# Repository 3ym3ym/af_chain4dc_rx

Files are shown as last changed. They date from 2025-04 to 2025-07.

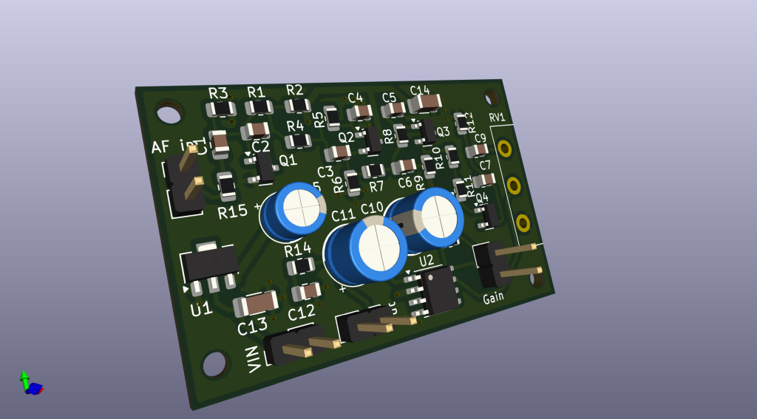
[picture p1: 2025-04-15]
aud_chain2_3d.png

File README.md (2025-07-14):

# af_chain4dc_rx
AF chain for DC receiver
aud_chain2

This little project was created to complete the standalone direct conversion (DC) receiver. Other parts of the receiver are:
 - Main board (input filter, quadrature mixer, AF preamps, phasing SSB demodulator). Si5351A board from Adafruit (or Aliexpress clone) is attached to it.
 - Control board. Can be any microcontroller running the qudrature VFO code. I am currently using RP2040 SuperMini, 0.96" SSD1306 OLED display and 360PPI optical encoder.

The idea behind the whole project is to build a high performance SSB/CW receiver using only cheap parts readily available from Aliexpress or other similar sources.

Included files are the KiCAD 9.0 project (schematic and PCB) which uses SMD footprints. It can be modified to use through hole footprints. All parts are available in TH variants.

The first stage is a simple CE amplifier, also used to set the bias point to the following filter stages. The gain (and the input impedance) is set by R15.

I picked the idea of the low-pass audio filter from Asshar Farhan, VU2ESE. The actual filter design was done using the online Filter Wizard tool from Analog Devices, then tweaked while simulating in LTSpice. The values listed in the schematic result in -3dB point about 2.0kHz. At 5kHz the attenuation is -50dB. I used 5% resistors and 10% capacitors. The frequency response is not as sharp as the simulated with the ideal values, but is good enough and I like the sound of SSB coming through the filter. I am not a CW guy, modifying the filter for CW is left as an exercise for the reader.

The final amplifier is a standard TDA2822 circuit, with a jumper to change the gain. It has significantly lower hiss than LM386 and the Chinese fakes seem to work well.

The circuit works down to 3V. I am using a cheap ME6209 3.3V LDO, which requires a good output bypass capacitor, otherwise there is a bit of ringing at the maximum volume (because of the feedback from the PA back to the input stage through the power rail). 100uF aluminum plus 10uF ceramic capacitors is not an overkill.

ME6209 claims to tolerate up to 18V input, which I haven't tested. The dropout is small enough to use a single LiIon cell as the input power source, or 12V if that is what you have in the receiver.

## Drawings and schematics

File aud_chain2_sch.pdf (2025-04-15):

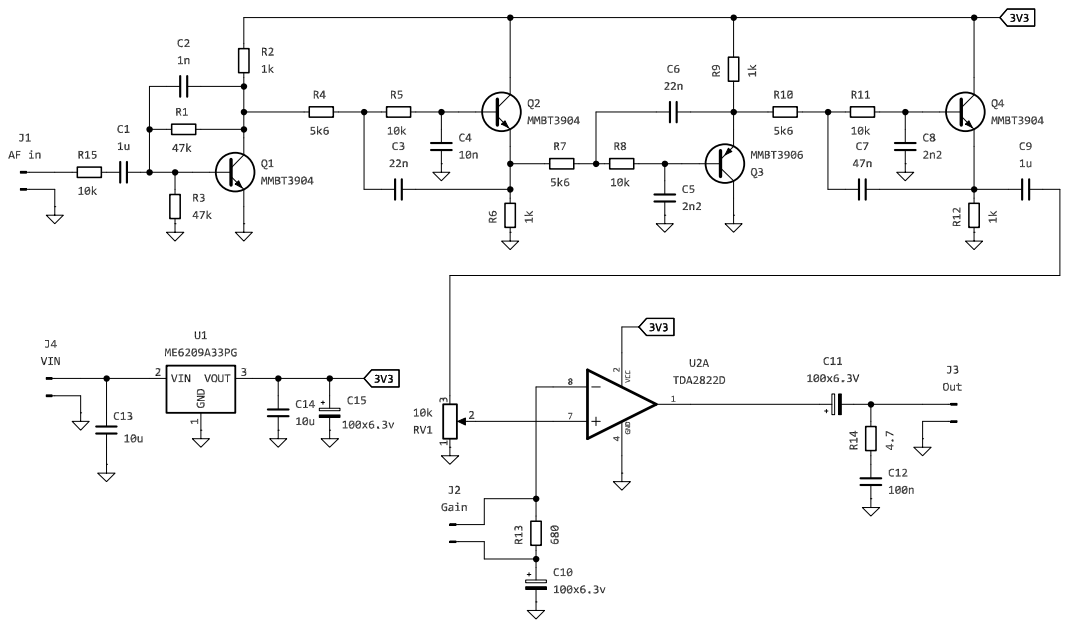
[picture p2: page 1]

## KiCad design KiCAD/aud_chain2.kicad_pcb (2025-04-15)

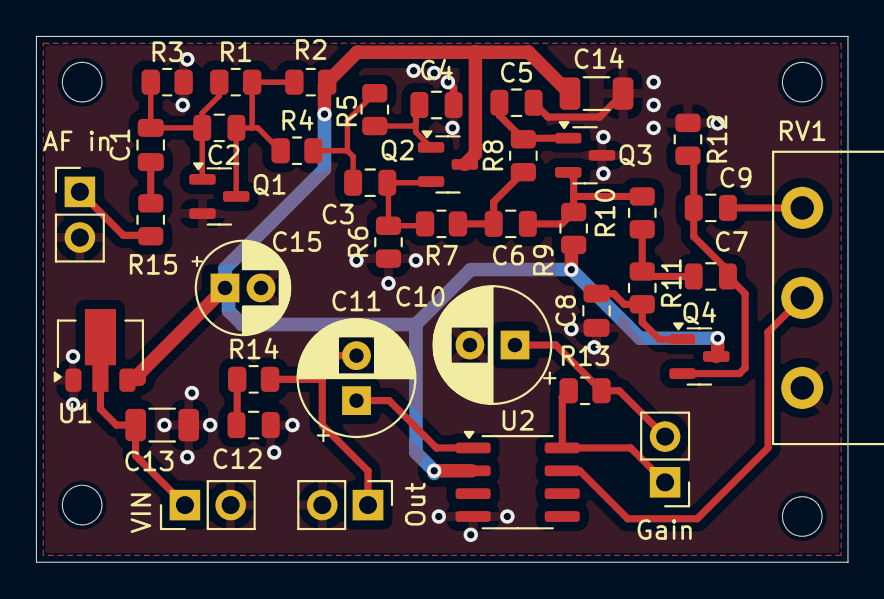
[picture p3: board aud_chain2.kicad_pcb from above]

Board: 2 copper layers, 45.1 x 29.2 mm, 41 parts (0 on the bottom side), 23 nets.

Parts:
C1, C9: 1u; C_0805_2012Metric
C2, C4: 1n; C_0805_2012Metric
C3, C6, C7: 22n; C_0805_2012Metric
C5: 10n; C_0805_2012Metric
C8: 15n; C_0805_2012Metric
C10: 100x6.3v; CP_Radial_D6.3mm_P2.50mm
C11: 100x6.3V; CP_Radial_D6.3mm_P2.50mm
C12: 100n; C_0805_2012Metric
C13, C14: 10u; C_1206_3216Metric
C15: 47x6.3v; CP_Radial_D5.0mm_P2.00mm
J1: AF in; PinHeader_1x02_P2.54mm_Vertical
J2: Gain; PinHeader_1x02_P2.54mm_Vertical
J3: Out; PinHeader_1x02_P2.54mm_Vertical
J4: VIN; PinHeader_1x02_P2.54mm_Vertical
Q1, Q2, Q4: MMBT3904; SOT-23
Q3: MMBT3906; SOT-23
R1, R3: 47k; R_0805_2012Metric
R2, R6, R9, R12: 1k; R_0805_2012Metric
R4, R15: 10k; R_0805_2012Metric
R5: 27k; R_0805_2012Metric
R7: 3k9; R_0805_2012Metric
R8, R11: 5k6; R_0805_2012Metric
R10: 2k4; R_0805_2012Metric
R13: 680; R_0805_2012Metric
R14: 4.7; R_0805_2012Metric
RV1: 10k; Potentiometer_Piher_PC-16_Single_Horizontal
U1: ME6209; SOT-89-3
U2: TDA2822D; SOIC-8_3.9x4.9mm_P1.27mm

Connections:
3V3: C14.1, C15.1, Q2.3 (C), Q4.3 (C), R2.1, R9.2, U1.3 (VOUT), U2.2
GND: C4.1, C5.1, C8.1, C10.2, C12.1, C13.2, C14.2, C15.2, J1.2, J3.2, J4.2, Q1.2 (E), Q3.3 (C), R3.2, R6.1, R12.1, RV1.1, U1.1 (GND), U2.4
unnamed: C1.1, R15.2
unnamed: C3.1, R4.2, R5.1
unnamed: C6.1, R7.2, R8.1
unnamed: C7.1, R10.2, R11.1
unnamed: C9.2, RV1.3
unnamed: C11.1, U2.1
unnamed: C12.2, R14.1
unnamed: J1.1, R15.1
unnamed: J2.1, R13.2, U2.8
unnamed: C10.1, J2.2, R13.1
unnamed: C11.2, J3.1, R14.2
unnamed: C13.1, J4.1, U1.2 (VIN)
unnamed: C1.2, C2.2, Q1.1 (B), R1.1, R3.1
unnamed: C2.1, Q1.3 (C), R1.2, R2.2, R4.1
unnamed: C4.2, Q2.1 (B), R5.2
unnamed: C3.2, Q2.2 (E), R6.2, R7.1
unnamed: C5.2, Q3.1 (B), R8.2
unnamed: C6.2, Q3.2 (E), R9.1, R10.1
unnamed: C8.2, Q4.1 (B), R11.2
unnamed: C7.2, C9.1, Q4.2 (E), R12.2
unnamed: RV1.2, U2.7
